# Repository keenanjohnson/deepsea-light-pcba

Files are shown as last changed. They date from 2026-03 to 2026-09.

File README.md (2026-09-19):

# deepsea-light-pcba
A PCB for controlling Deepsea Lights

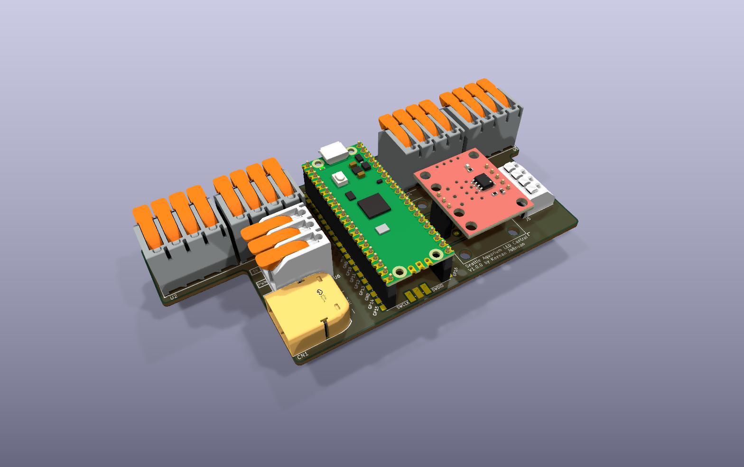
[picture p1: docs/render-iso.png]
3D view of the board


<p align="center">
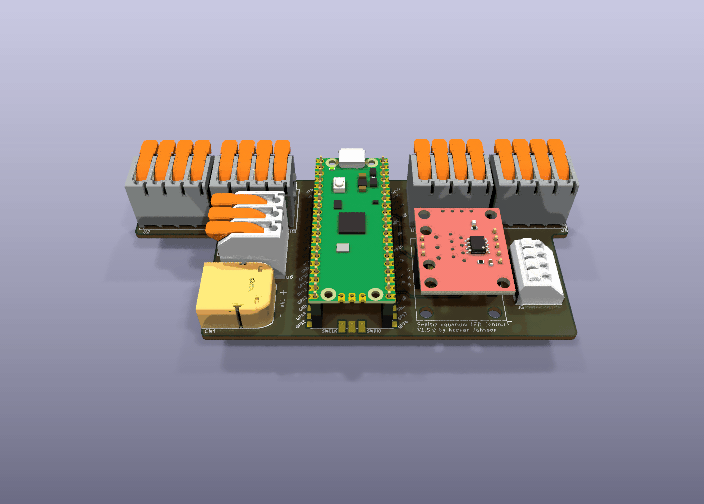
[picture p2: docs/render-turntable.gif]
Board turntable
  
</p>

| Top | Bottom |
|-----|---|
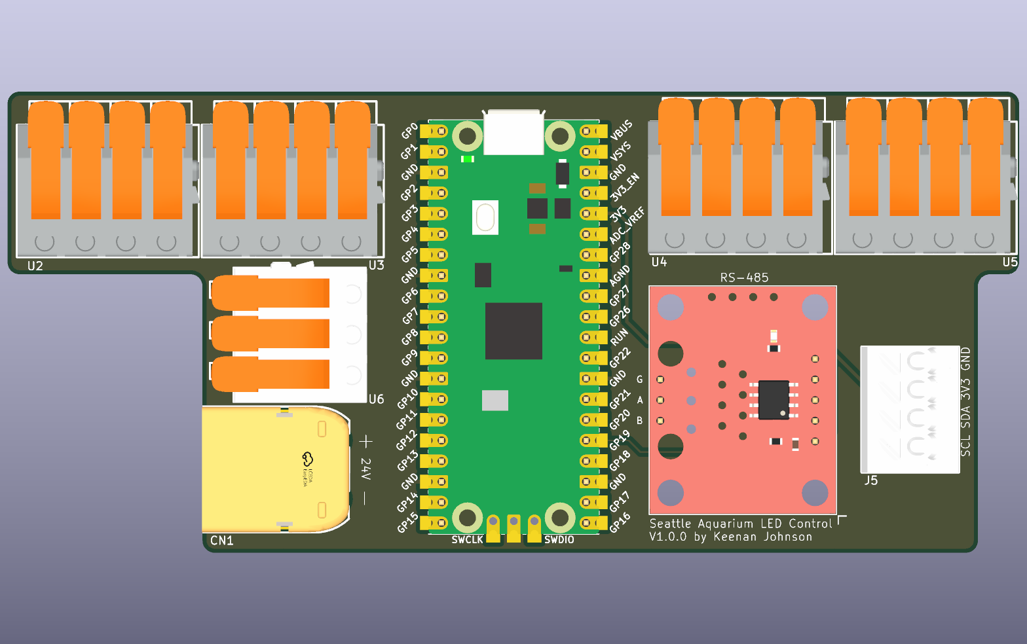
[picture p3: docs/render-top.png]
Top view
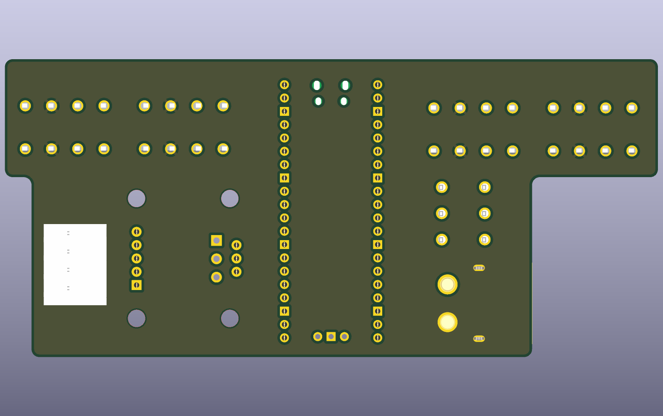
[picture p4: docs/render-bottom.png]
Bottom view
|  |  |

The 3D views come from `scripts/render.py`, which drives KiCad's ray tracer
(`kicad-cli pcb render`) and stitches the turntable frames with ffmpeg. The
same script exports the schematic below. The
[Renders workflow](.github/workflows/renders.yml) re-runs it, and the connector
overview, whenever the board or schematic changes and commits the results to
`docs/`.

## Schematic

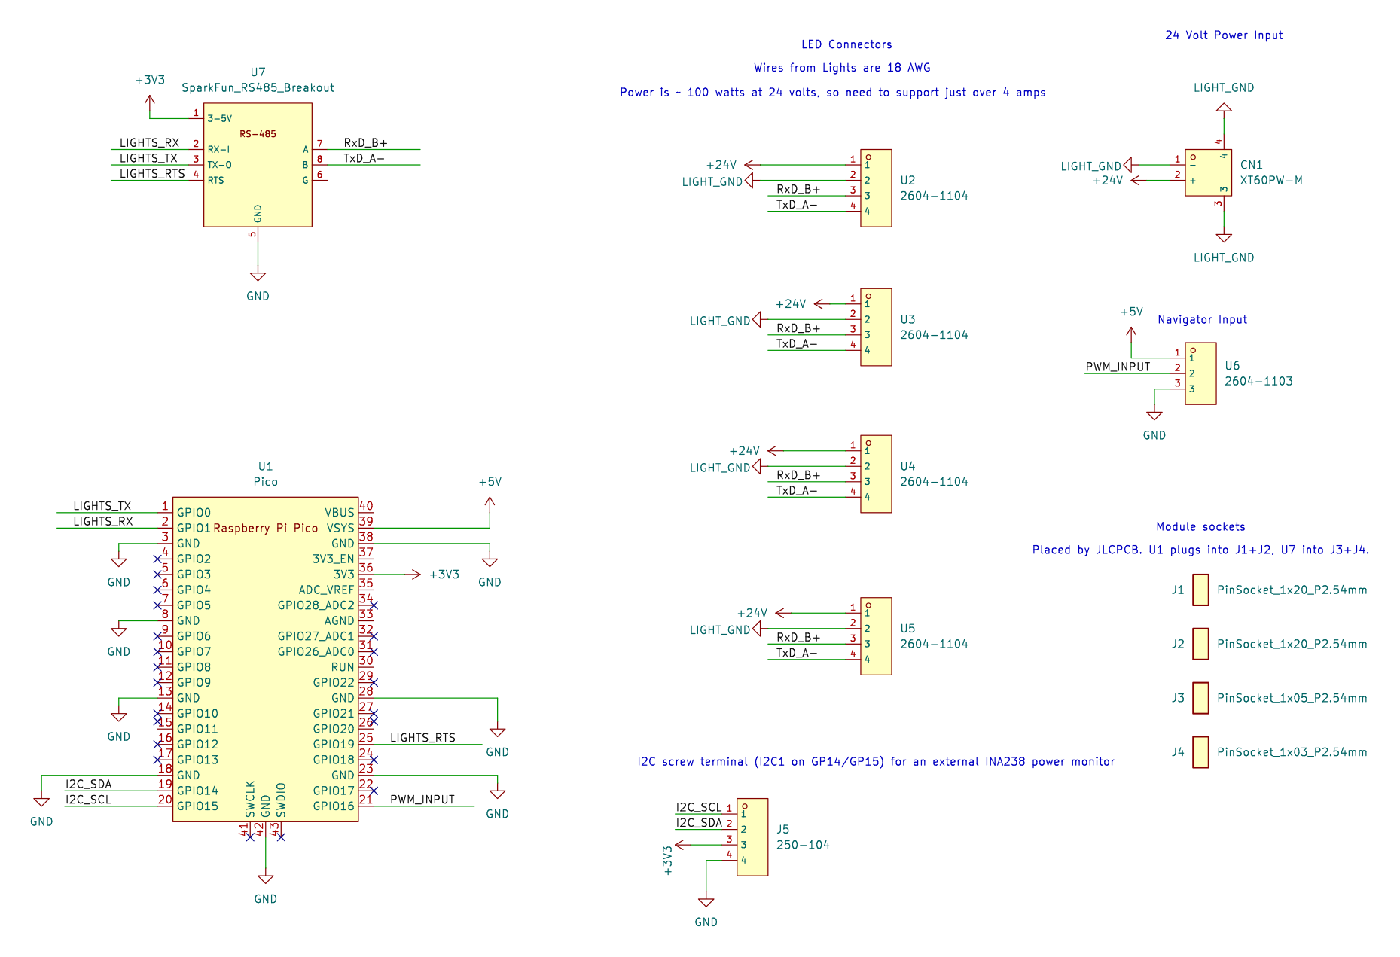
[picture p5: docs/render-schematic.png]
Schematic


## Connectors

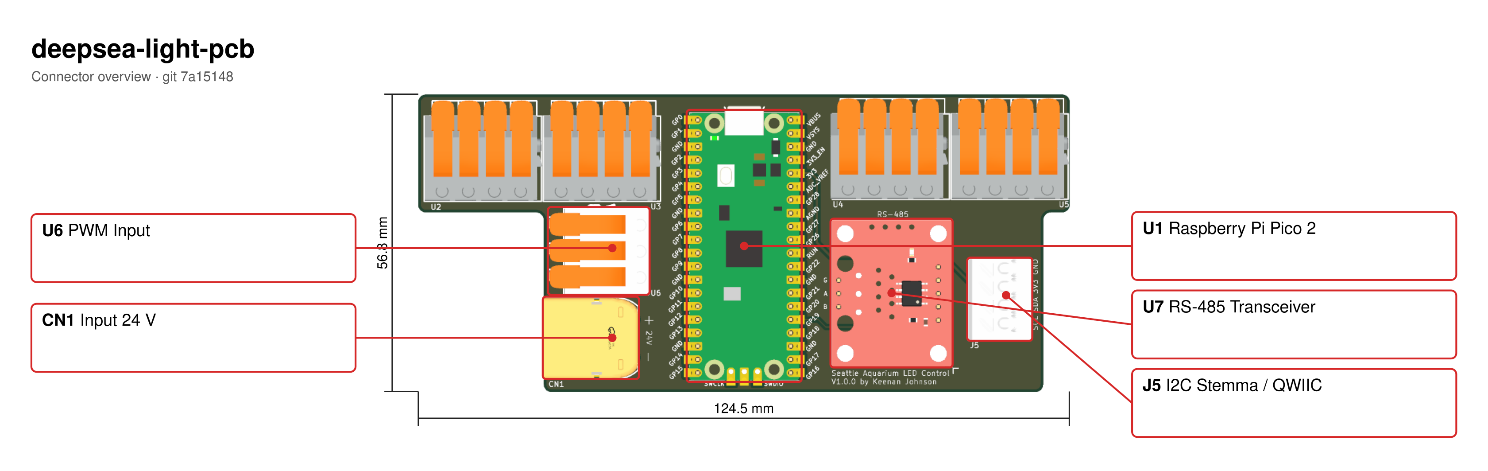
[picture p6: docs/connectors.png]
Connector overview


Rendered automatically by [kicad-callouts](https://github.com/keenanjohnson/kicad-callouts) via GitHub Actions whenever the board changes.

## Fabrication

Generate everything needed to order the board from JLCPCB:

```
scripts/generate_fab.py
```

This writes to `fab/` (gitignored): a flat `*-gerbers.zip` to upload, the same
gerbers and Excellon drill files loose for inspection, a BOM with LCSC part
numbers, a position file for assembly, a schematic PDF, and the DRC/ERC
reports.

The BOM and position file are produced by
[Fabrication-Toolkit](https://github.com/bennymeg/Fabrication-Toolkit), which
applies JLCPCB's part rotation conventions. The script fetches it at a pinned
release into `.fabrication-toolkit/` (gitignored) on first run. It needs a
Python that can import `pcbnew`; on macOS the script finds KiCad's bundled one.
If a part still arrives rotated, add an `FT Rotation Offset` field (degrees,
counter-clockwise) to that symbol and regenerate.

The Pico (U1) and the SparkFun RS-485 breakout (U7) are off-the-shelf modules
that plug into female 2.54 mm headers, so they are excluded from the BOM and
position file. The headers themselves are J1–J4: pad-less footprints
(`Socket_1x*_P2.54mm_NoPads`) placed over the module pin rows, carrying the
LCSC numbers so JLCPCB solders the sockets and the modules are fitted by hand.

J5 is a 4-pole 2.54 mm screw terminal on the right edge carrying I2C1 (GP14
SDA, GP15 SCL) plus 3.3 V and ground, for an external INA238 power monitor
module such as the Adafruit breakout. The firmware expects that sensor at
address 0x40 and tolerates its absence.

Design rule and unrouted-connection errors abort the export. ERC errors are
reported but do not, since the remaining ones are annotation issues such as
missing power flags; pass `--strict` to block on those too. Silkscreen warnings
are expected: several footprint libraries use legend text below JLCPCB's 1.0 mm
minimum height and 0.15 mm minimum stroke.

Order settings that match the design rules in `deepsea-light-pcb.kicad_pro`:
**4 layers, 1.6 mm thick, 1 oz outer copper.** The [Fab files
workflow](.github/workflows/fab.yml) builds the same package in CI and attaches
it to release tags.

## Stackup

| Layer  | Net | Purpose |
|---|---|---|
| F.Cu | `GND` | Logic ground, 0.1 mm above the signal layer so the PWM input and UART reference a quiet plane |
| In1.Cu | `GND` | Logic ground, carries most of the signal routing |
| In2.Cu | `+24V` | Light supply |
| B.Cu | `LIGHT_GND` | Light return, tightly coupled to the 24 V plane above it |

`GND` and `LIGHT_GND` are deliberately separate on the board. The Pico and the
RS-485 transceiver run from the Navigator's 5 V supply, with 24 V reaching only
the light connectors, following the bench testing in
[CCR_development#34](https://github.com/Seattle-Aquarium/CCR_development/issues/34#issuecomment-4383756606)
that traced light flicker to shared power. There are no ground stitching vias:
JLCPCB does not offer blind or buried vias, so stitching would have to punch
both power planes and put `GND` within clearance of `LIGHT_GND` at every drop.
The two ground pours meet at the through-hole ground pins instead.

The `Power` netclass gives `+24V` and `LIGHT_GND` a 0.5 mm clearance, wider than
the 0.09 mm JLCPCB allows, because those nets land on hand-soldered terminal
blocks where a bridge to the ground pour would put 24 V on the Pico.

### Software Repo

This board is designed to run micropython from this repo: https://github.com/Seattle-Aquarium/CCR_ROV_survey_methods/tree/main/lighting/code

## Random Notes

I usually use this project to get parts / footprints:

https://github.com/TousstNicolas/JLC2KiCad_lib

### Example usage

JLC2KiCadLib C3818565        -dir Deepsea_light_lib            \
                             -model_dir Deepsea_light_dir      \
                             -footprint_lib Deepsea_light_lib  \
                             -symbol_lib_dir Deepsea_light_dir \
                             -symbol_lib Deepsea_light_lib

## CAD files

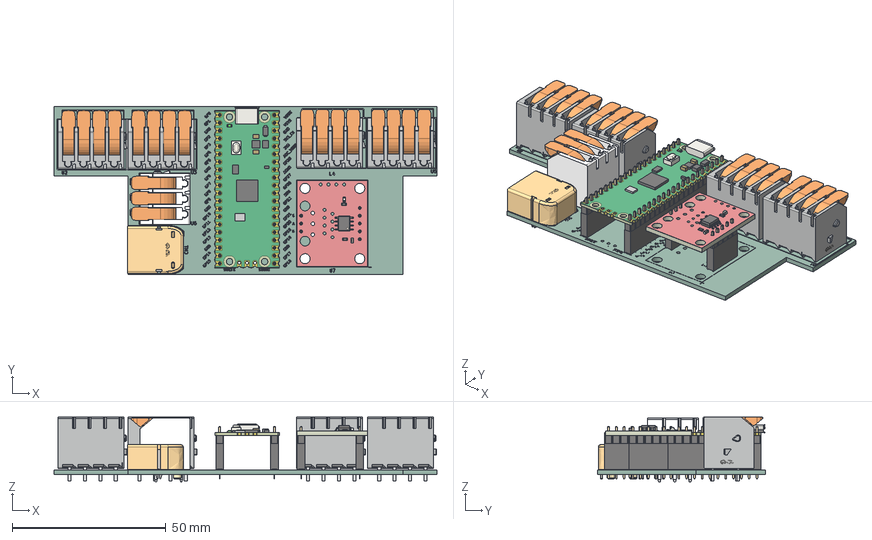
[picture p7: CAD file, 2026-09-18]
deepsea-light-pcb.step
124.5 x 54.5 x 21.0 mm
CONN-TH_2604-1104 x 4
RaspberryPi_Pico_Module_KiCad
PinSocket_1x20_P2.54mm_Vertical x 2
PinHeader_1x20_P254mm_Vertical x 2
SOIC-8_3.9x4.9mm_P1.27mm
R_0603_1608Metric x 2
LED_0603_1608Metric
C_0603_1608Metric
module_soldermask x 2
module_PCB
PinSocket_1x05_P2.54mm_Vertical
PinHeader_1x05_P254mm_Vertical
PinSocket_1x03_P2.54mm_Vertical
PinHeader_1x03_P254mm_Vertical
C3309758-2604-1103
CONN-TH_XT60PW-M
deepsea-light-pcb_silkscreen
deepsea-light-pcb_PCB

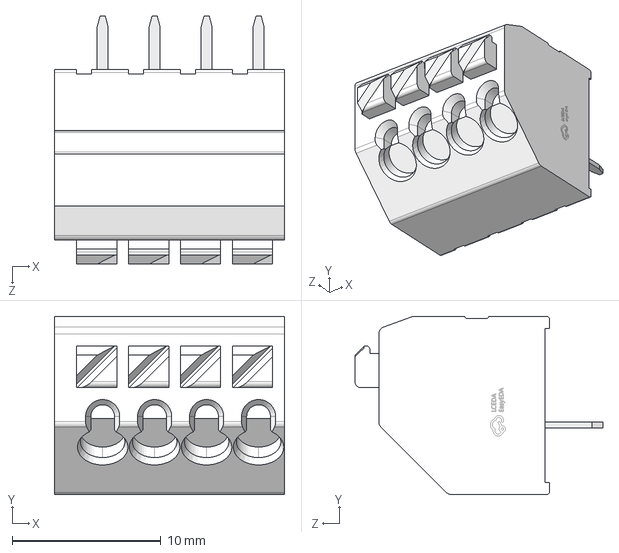
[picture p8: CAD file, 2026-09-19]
Deepsea_light_lib/Deepsea_light_lib/Deepsea_light_dir/CONN-TH_4P-P3.50_250-104.step
15.5 x 12.0 x 16.7 mm

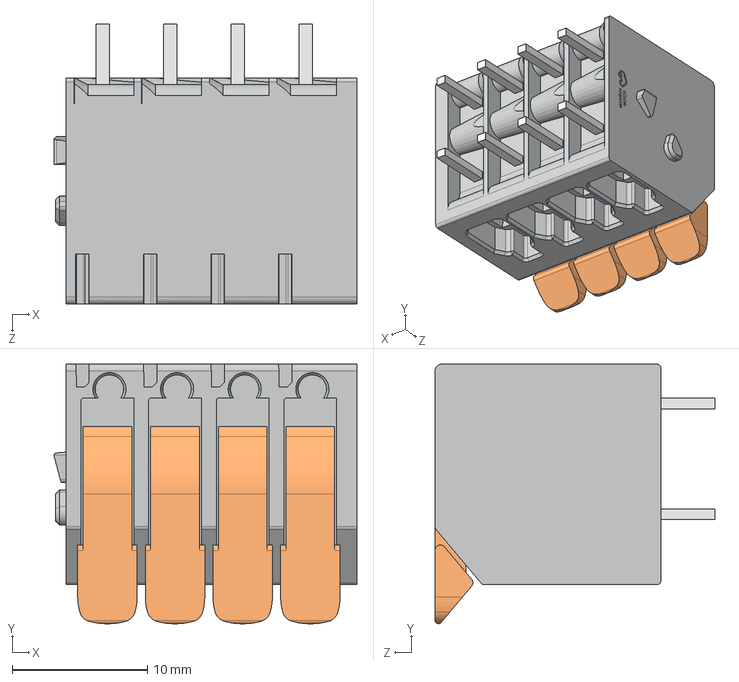
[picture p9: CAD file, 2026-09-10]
Deepsea_light_lib/Deepsea_light_lib/Deepsea_light_dir/CONN-TH_2604-1104.step
22.4 x 19.2 x 20.7 mm

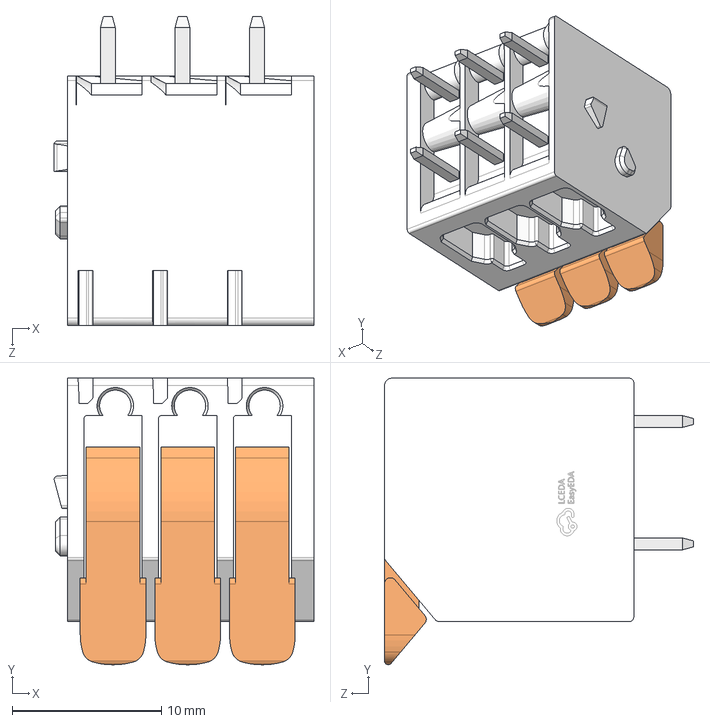
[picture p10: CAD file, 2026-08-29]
Deepsea_light_lib/Deepsea_light_lib/Deepsea_light_dir/CONN-TH_2604-1103.step
17.4 x 19.2 x 20.7 mm

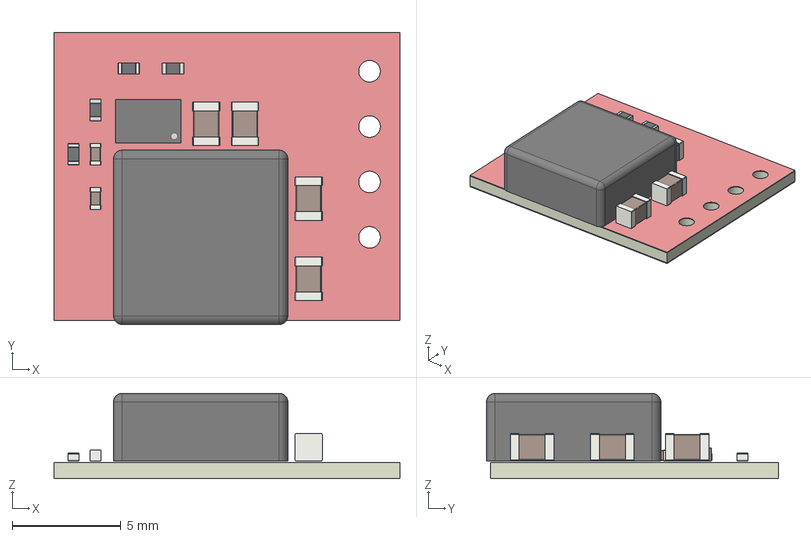
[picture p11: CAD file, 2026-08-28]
Deepsea_light_lib/Deepsea_light_lib/Deepsea_light_dir/SparkFun_BabyBuck_5V.step
15.9 x 13.4 x 3.96 mm
C_0402_1005Metric x 2
C_0805_2012Metric x 4
R_0402_1005Metric x 4
L_Coilcraft_XAL7030-562
DFN-8-1EP_3x2mm_P0.5mm_EP1.3x1.5mm
babybuck_module_soldermask x 2
babybuck_module_PCB

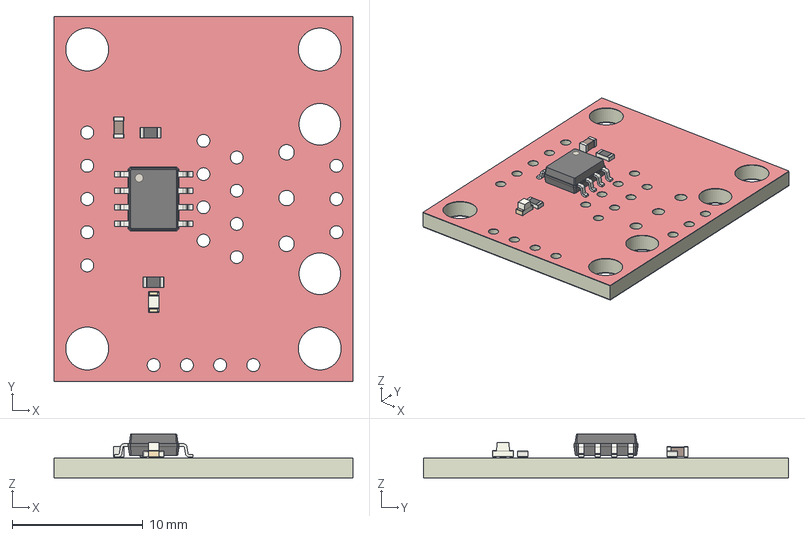
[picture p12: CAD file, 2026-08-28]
Deepsea_light_lib/Deepsea_light_lib/Deepsea_light_dir/SparkFun_RS485_Breakout.step
22.9 x 27.9 x 3.42 mm
SOIC-8_3.9x4.9mm_P1.27mm
R_0603_1608Metric x 2
LED_0603_1608Metric
C_0603_1608Metric
module_soldermask x 2
module_PCB

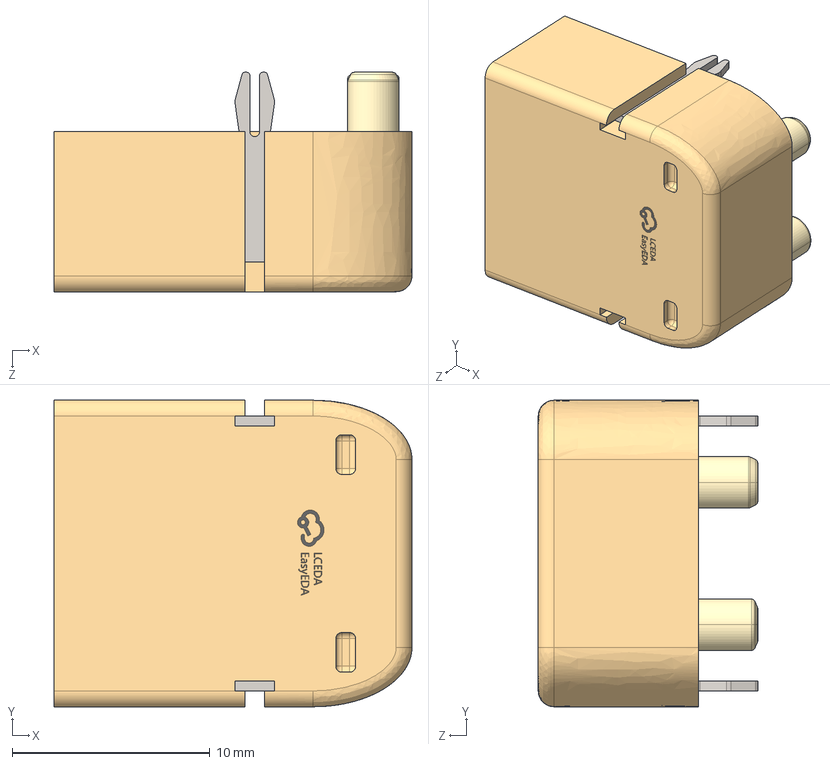
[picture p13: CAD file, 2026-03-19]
Deepsea_light_lib/Deepsea_light_lib/Deepsea_light_dir/CONN-TH_XT60PW-M.step
18.1 x 15.5 x 11.1 mm

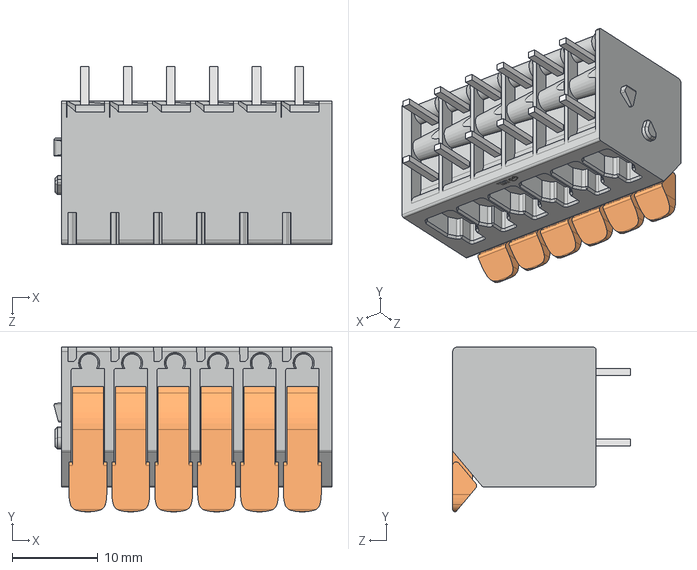
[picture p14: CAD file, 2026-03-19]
Deepsea_light_lib/Deepsea_light_lib/Deepsea_light_dir/CONN-TH_2604-1106.step
32.4 x 19.2 x 20.7 mm

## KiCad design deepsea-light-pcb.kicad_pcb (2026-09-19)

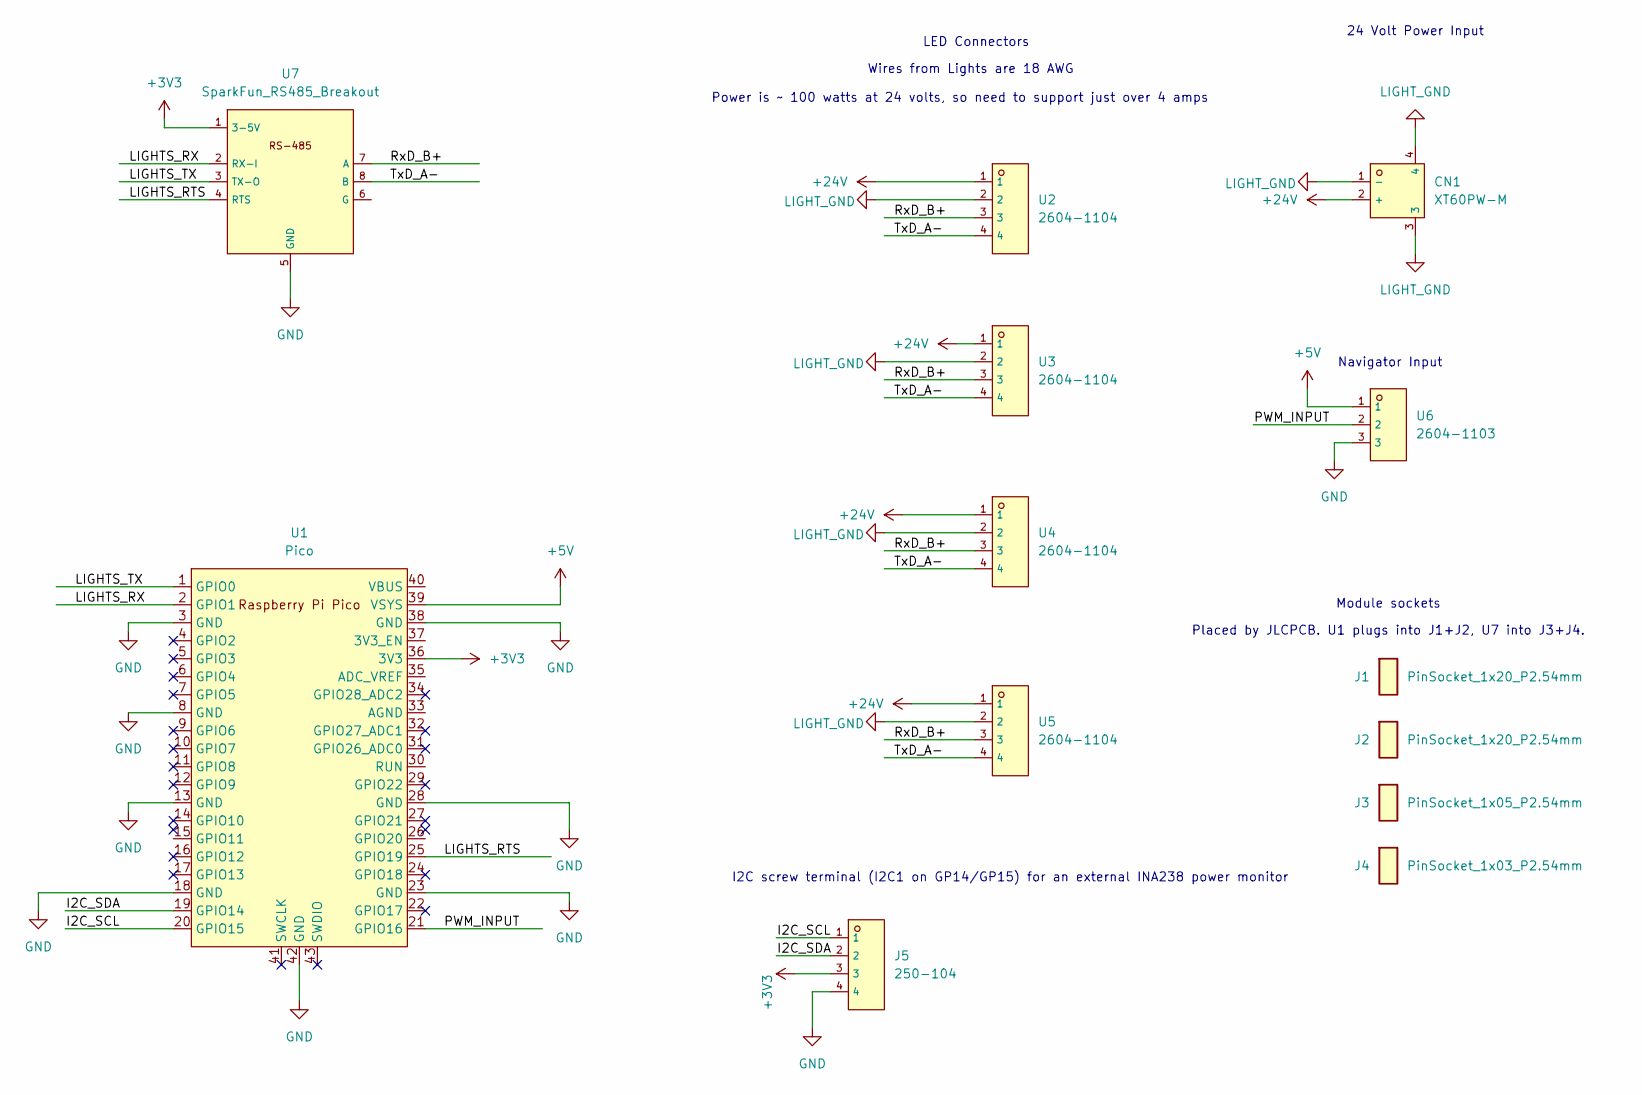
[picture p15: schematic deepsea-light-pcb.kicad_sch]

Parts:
CN1: XT60PW-M; CONN-TH_XT60PW-M; LCSC C98732
J1, J2: PinSocket_1x20_P2.54mm; Socket_1x20_P2.54mm_NoPads; LCSC C124410
J3: PinSocket_1x05_P2.54mm; Socket_1x05_P2.54mm_NoPads; LCSC C124414
J4: PinSocket_1x03_P2.54mm; Socket_1x03_P2.54mm_NoPads; LCSC C146690
J5: 250-104; CONN-TH_4P-P3.50_250-104; LCSC C3310053
U1: Pico; RPi_Pico_SMD_TH
U2, U3, U4, U5: 2604-1104; CONN-TH_2604-1104; LCSC C3309598
U6: 2604-1103; CONN-TH_2604-1103; LCSC C3309758
U7: SparkFun_RS485_Breakout

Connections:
+3V3: J5.3, U1.36 (3V3), U7.1 (3-5V)
+5V: U1.39 (VSYS), U6.1
+24V: CN1.2 (+), U2.1, U3.1, U4.1, U5.1
/I2C_SCL: J5.1, U1.20 (GPIO15)
/I2C_SDA: J5.2, U1.19 (GPIO14)
/LIGHTS_RTS: U1.25 (GPIO19), U7.4 (RTS)
/LIGHTS_RX: U1.2 (GPIO1), U7.2 (RX-I)
/LIGHTS_TX: U1.1 (GPIO0), U7.3 (TX-O)
/PWM_INPUT: U1.21 (GPIO16), U6.2
/RxD_B+: U2.3, U3.3, U4.3, U5.3, U7.7 (A)
/TxD_A-: U2.4, U3.4, U4.4, U5.4, U7.8 (B)
GND: J5.4, U1.3 (GND), U1.8 (GND), U1.13 (GND), U1.18 (GND), U1.23 (GND), U1.28 (GND), U1.38 (GND), U1.42 (GND), U6.3, U7.5 (GND)
LIGHT_GND: CN1.1 (-), CN1.3, CN1.4, U2.2, U3.2, U4.2, U5.2

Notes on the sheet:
24 Volt Power Input
Navigator Input
Module sockets
Placed by JLCPCB. U1 plugs into J1+J2, U7 into J3+J4.
Power is ~ 100 watts at 24 volts, so need to support just over 4 amps
Wires from Lights are 18 AWG
LED Connectors
I2C screw terminal (I2C1 on GP14/GP15) for an external INA238 power monitor

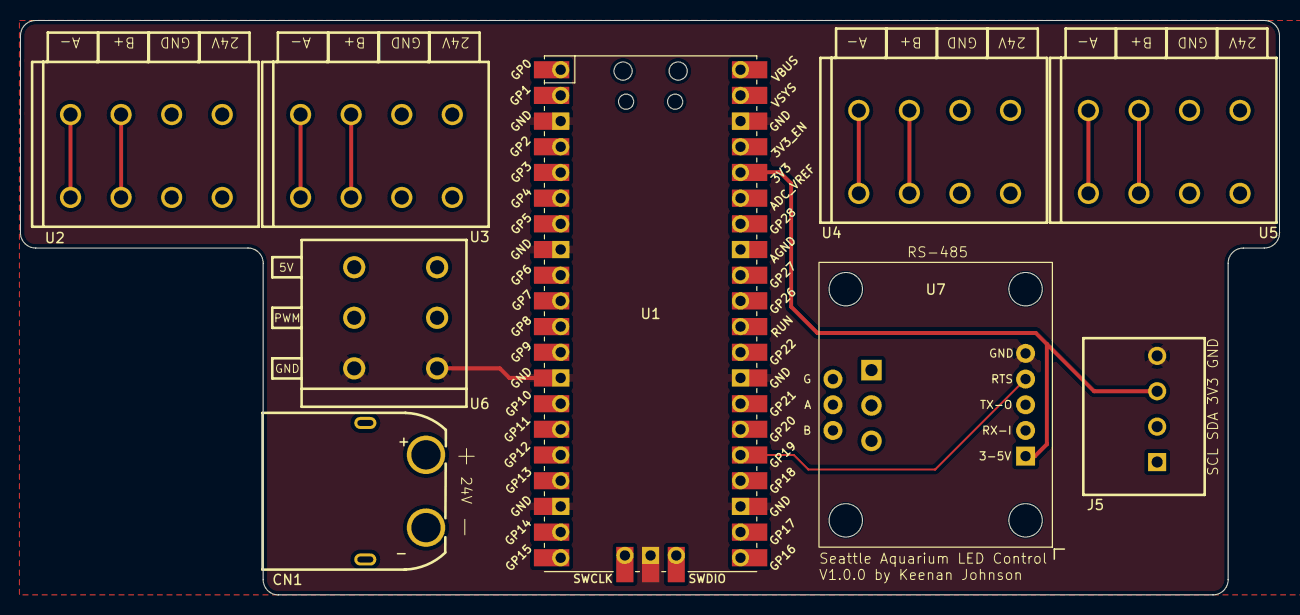
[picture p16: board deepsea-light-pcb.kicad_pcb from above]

Board: 4 copper layers, 124.5 x 56.8 mm, 13 parts (0 on the bottom side), 13 nets.

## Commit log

2026-03-18 Empty project
    [deepsea-light-pcb.kicad_pcb, deepsea-light-pcb.kicad_sch]
2026-03-18 Board outline
    [deepsea-light-pcb.kicad_pcb]
2026-03-18 Add basic board outline
    [deepsea-light-pcb.kicad_pcb]
2026-03-19 Add correct pico footprint
    [deepsea-light-pcb.kicad_pcb, deepsea-light-pcb.kicad_sch]
2026-03-19 Placement work
    [CONN-TH_2604-1106.step, CONN-TH_XT60PW-M.step, deepsea-light-pcb.kicad_pcb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]
2026-05-21 Fix 3d model and update to kicad 10
    [deepsea-light-pcb.kicad_pcb]
2026-05-21 More updates to kicad 10
    [deepsea-light-pcb.kicad_sch]
2026-08-27 Fix 3d export
    [deepsea-light-pcb.kicad_pcb, deepsea-light-pcb.kicad_sch]
2026-08-27 Add note on wire gauge
    [deepsea-light-pcb.kicad_sch]
2026-09-08 Update connector render
2026-09-08 Add connector render script
2026-09-08 Render preview + Callout Updates (#1)
    * Add pcb render preview
    * Add callouts for all components
    * Update connector render
    * Update connector render
    * Update
    * Update deepsea-light-pcb.kicad_sch
    * Update connector render [skip ci]
    [deepsea-light-pcb.kicad_pcb, deepsea-light-pcb.kicad_sch]
2026-09-09 Update light pcb for more inward pico (#2)
    * Update light pcb
    * Add headers to 3d export
    * Update step
    ---------
    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
    [deepsea-light-pcb.kicad_pcb, deepsea-light-pcb.step]
2026-09-09 Routing progress
    [deepsea-light-pcb.kicad_pcb, deepsea-light-pcb.kicad_sch]
2026-09-09 Update connector render [skip ci]
2026-09-10 Add 4 pin connector
    [CONN-TH_2604-1104.step]
2026-09-19 Add JLCPCB fab Generation (#3)
    * Add fab to gitignore
    * Update .gitignore
    * Add basic gihub CI for fab export
    * Routing progress
    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
    [deepsea-light-pcb.kicad_pcb]
2026-09-19 Round the corners (#4)
    * Round the corners
    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
    [deepsea-light-pcb.kicad_pcb]
2026-09-19 Fix silkscreen
    [deepsea-light-pcb.kicad_pcb]
2026-09-19 Populate headers for fab only (#5)
    * Populate headers for fab only
    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
    [deepsea-light-pcb.kicad_pcb, deepsea-light-pcb.kicad_sch]
2026-09-19 Fix header rotation
    [deepsea-light-pcb.kicad_pcb, deepsea-light-pcb.kicad_sch]
2026-09-19 Fix solder connections
    [deepsea-light-pcb.kicad_pcb, deepsea-light-pcb.kicad_sch]
2026-09-19 Add stemma connector for i2c (#6)
    * Add stemma
    * Fix warning
    * Add callout
    * Fix warning
    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
    [CONN-TH_4P-P3.50_250-104.step, deepsea-light-pcb.kicad_pcb, deepsea-light-pcb.kicad_sch]
2026-09-19 Add schematic render
2026-10-28 Replace connector (#9)
    * Replace connector
    * Update renders [skip ci]
    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
2026-10-28 Fix connector rotation
